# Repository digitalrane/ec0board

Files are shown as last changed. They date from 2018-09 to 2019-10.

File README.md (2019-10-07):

ec0board
========

ec0board is a personal project to replace the dead control board in my otherwise landfill Kogan TKL mechanical keyboard.
It was designed to occupy the exact same physical dimensions, and have the exact same key switch spacing as the original board, however has a much more powerful user-controlled MCU.
The MCU used is an AT90USB1286, chosen for the number of GPIOs, enabling NKRO to be achieved. It uses a diode matrix to connect the key switches, and takes Cherry-MX compatible key switches (I use browns).
Support is being added to the open source QMK firmware for this board, as the intention is to run a completely open keyboard replacement.

The board supports a switchable backlight, and additional RGB LED underneath the board (to see if the controller is alive, basically) and switchable backlights for the Fn, Caps, Scroll and Num lock keys independently to the main backlight.

This board uses custom footprints and 3d models for the following. If you find any of them missing from this repository, please file an issue.
* Cherry MX Brown switch model and footprint
* AT90USB1286 model and footprint
* Ingwaz rune (because I like to ensure runes or sigils cover my electronics for great ~ mystical power ~)

Versions
========

* v0: Original prototype, ended up not working reliably because I goofed the electron-herding aspects of this version.
* v1: Original replacement. Found the Micro USB connector to be flimsy, because Micro USB is a bit crap. Also had a testing RGB LED space,
  which never worked right. Other than that, fairly reliable, but still relied on the Kogan TKL or similar cheap Aliexpress/eBay donor KB.
* v2: Never released or manufactured, added standalone supports, rerouted entire keyboard to use newly added standard KiCad key switch
  footprints, generally cleaned up routing. Started moving toward a Mini USB connector to address connector stability.
* v3: Decided to use USB-C during a dream, so rewired the whole power supply and USB connection section. Further routing improvements.
  Cleaned up all footprints, values, and added better more descriptive values to components so a proper BOM could be generated. Generated a
  proper BOM with the Interactive HTML BOM KiCad plugin. Updated everything for KiCad 5.1 and added some more 3D models. All required
  libraries are now in KiCad or this repo.

Firmware
========

This keyboard uses QMK, and a board definition and configuration is included in the `qmk_ec0board` directory. Drop this into QMK and set
your keyboard type to 'ec0board' on the make commandline as documented [here](https://beta.docs.qmk.fm/detailed-guides/getting_started_make_guide).

e.g.:
`make ec0board`

Flashing
========

Programming of the firmware is done via the ISP header. You will need a standard AVR ISP programmer, I use an Olimex unit. They keyboard
should not be powered via USB whilst flashing, but you won't get magic smoke if you do it accidentally (yeah I tried it, so what, are you a
cop?).

Fuses
=====

The fuses on your AT90USB1286 should be set for external crystal oscillator operation, with JTAG disabled, to free up enough GPIOs. We
also want SPIEN set so we can use the ISP to flash/recover the chip.

The fules should be set to -
(E:F3, H:D9, L:DE)

BOM
===

Thanks to the wonderful [InteractiveHtmlBom](https://github.com/openscopeproject/InteractiveHtmlBom) KiCad plugin, this repository now
contains a really nice HTML BOM. You can clone this repo and browse it locally in the `bom` directory, or download/view it from
[here](https://rawcdn.githack.com/devec0/ec0board/master/bom/ibom.html).

For U1, AT90USB1286 is the sensible option, because no keyboard needs the host mode support of AT90USB1287.
If you need host mode, you're an absolute maniac. I want to know what you're up to, get in touch!

TODO
====

* Finish code for lighting backlight behind Capslock, Scrolllock, Numlock and the Function key when engaged
* Finish code to get the Function key working correctly

And another thing
=================

<3

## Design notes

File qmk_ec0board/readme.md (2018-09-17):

# ec0board

ec0board

A QMK replacement board for various TK529U mechanical keyboards.
Tried and tested as a replacement PCB in the Kogan TKL.

Keyboard Maintainer: [ec0](https://github.com/devec0)
Hardware Supported: ec0board v1 PCB
Hardware Availability: [DIY](http://github.com/devec0/ec0board)

Make example for this keyboard (after setting up your build environment):

    make ec0board:default

See [build environment setup](https://docs.qmk.fm/build_environment_setup.html) then the [make instructions](https://docs.qmk.fm/make_instructions.html) for more information.

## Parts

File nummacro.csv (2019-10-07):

Id | Designator | Package | Quantity | Designation | Supplier and ref
1 | SW1 | SW_SPST_EVQQ2 | 1 | RESET
2 | SW2 | SW_SPST_EVQQ2 | 1 | HWB
3 | SW_ESC1 | SW_Cherry_MX1A_1.00u_PCB | 1 | ESC
4 | G*** | ingwaz | 1 | LOGO
5 | REF** | OSHW-Logo2_14.6x12mm_SilkScreen | 1 | OSHW-Logo2_14.6x12mm_SilkScreen
6 | J1 | USB_C_Receptacle_GCT_USB4085 | 1 | GCT USB4085
7 | D88 | D_PowerDI-123 | 1 | MBR130LSFT1G
8 | C8 | C_0805_2012Metric_Pad1.15x1.40mm_HandSolder | 1 | 10uF
9 | C7,C2,C3 | C_0805_2012Metric_Pad1.15x1.40mm_HandSolder | 3 | 100n
10 | D35,D50,D45,D40,D27,D22,D17,D11,D58,D18,D64,D68,D74,D75,D79,D84,D2,D7,D12,D82,D13,D1,D19,D71,D23,D65,D59,D53,D48,D43,D38,D32,D36,D76,D80,D85,D4,D9,D14,D20,D25,D30,D87,D28,D51,D56,D62,D66,D72,D77,D81,D86,D5,D10,D41,D21,D26,D31,D37,D42,D47,D52,D57,D63,D6,D16,D24,D29,D33,D39,D44,D49,D55,D60,D69,D46,D3,D8,D15,D34,D54,D61,D67,D73,D78,D83,D70 | D_MiniMELF | 87 | LL4148
11 | R5,R4 | R_0805_2012Metric_Pad1.15x1.40mm_HandSolder | 2 | 22r
12 | LED_TILDE1,LED_HOME1,LED_END1,LED_UP1,LED_DOWN1,LED_PAUSE1,LED_PGUP1,LED_PGDN1,LED_RIGHT1,LED_LEFT1,LED_F11,LED_DEL1,LED_INS1,LED_PRN1,LED_F12,LED_RCTL1,LED_BKSLSH1,LED_BKSPC1,LED_ENTER1,LED_RSHIFT1,LED_LSHIFT1,LED_SCRL1,LED_F2,LED_FN1,LED_FSLASH1,LED_COLON1,LED_F9,LED_UNDSCR1,LED_RSUP1,LED_LBRACE1,LED_QUOT1,LED_F10,LED_EQUAL1,LED_3,LED_I1,LED_P1,LED_PERIOD1,LED_RALT1,LED_0,LED_L1,LED_O1,LED_F8,LED_COMMA1,LED_9,LED_K1,LED_F7,LED_RBRACE1,LED_N1,LED_F6,LED_U1,LED_J1,LED_8,LED_7,LED_H1,LED_Y1,LED_F5,LED_SPACE1,LED_B1,LED_X1,LED_6,LED_D1,LED_F3,LED_4,LED_C1,LED_R1,LED_F0,LED_F4,LED_5,LED_V1,LED_T1,LED_G1,LED_S1,LED_LALT1,LED_W1,LED_Z1,LED_2,LED_F1,LED_A1,LED_Q1,LED_LSUP1,LED_1,LED_M1,LED_CAPS1,LED_E1,LED_ESC1,LED_LCTL1,LED_TAB1 | LED_D3.0mm | 87 | LED
13 | SW_LSHIFT1 | SW_Cherry_MX1A_2.25u_PCB | 1 | LSHIFT
14 | SW_ENTER1 | SW_Cherry_MX1A_2.25u_PCB | 1 | ENTER
15 | SW_RSHIFT1 | SW_Cherry_MX1A_2.75u_PCB | 1 | RSHIFT
16 | Q1 | SOT-23 | 1 | MMBT3904
17 | SW_9 | SW_Cherry_MX1A_1.00u_PCB | 1 | 9
18 | Y1 | Crystal_SMD_HC49-SD_HandSoldering | 1 | 16Mhz
19 | SW_RIGHT1 | SW_Cherry_MX1A_1.00u_PCB | 1 | RIGHT
20 | SW_8 | SW_Cherry_MX1A_1.00u_PCB | 1 | 8
21 | SW_7 | SW_Cherry_MX1A_1.00u_PCB | 1 | 7
22 | SW_6 | SW_Cherry_MX1A_1.00u_PCB | 1 | 6
23 | SW_5 | SW_Cherry_MX1A_1.00u_PCB | 1 | 5
24 | SW_4 | SW_Cherry_MX1A_1.00u_PCB | 1 | 4
25 | SW_3 | SW_Cherry_MX1A_1.00u_PCB | 1 | 3
26 | SW_2 | SW_Cherry_MX1A_1.00u_PCB | 1 | 2
27 | SW_1 | SW_Cherry_MX1A_1.00u_PCB | 1 | 1
28 | C6 | C_0805_2012Metric_Pad1.15x1.40mm_HandSolder | 1 | 1uF
29 | C5,C4 | C_0805_2012Metric_Pad1.15x1.40mm_HandSolder | 2 | 22pF
30 | CON1 | PinHeader_2x03_P2.54mm_Vertical | 1 | ISP
31 | R41,R8,R7,R6,R81,R82,R83,R84,R11,R12,R13,R14,R15,R16,R17,R18,R73,R63,R65,R20,R21,R22,R23,R24,R25,R26,R27,R28,R29,R64,R19,R32,R33,R34,R35,R36,R37,R38,R39,R40,R9,R30,R47,R48,R49,R50,R51,R53,R54,R55,R56,R46,R58,R59,R60,R61,R89,R90,R91,R92,R93,R57,R31,R67,R68,R69,R70,R71,R72,R62,R74,R75,R76,R77,R78,R79,R80,R52,R42,R43,R44,R66,R45,R85,R86,R87,R88 | R_0805_2012Metric_Pad1.15x1.40mm_HandSolder | 87 | 470
32 | U1 | QFP80P1600X1600X120-64N | 1 | AT90USB1286
33 | R2,R3 | R_0805_2012Metric_Pad1.15x1.40mm_HandSolder | 2 | 5.1k
34 | SW_A1 | SW_Cherry_MX1A_1.00u_PCB | 1 | A
35 | SW_B1 | SW_Cherry_MX1A_1.00u_PCB | 1 | B
36 | SW_BKSPC1 | SW_Cherry_MX1A_2.00u_PCB | 1 | BKSPC
37 | SW_BSLSH1 | SW_Cherry_MX1A_1.50u_PCB | 1 | BSLSH
38 | SW_C1 | SW_Cherry_MX1A_1.00u_PCB | 1 | C
39 | SW_CAPS1 | SW_Cherry_MX1A_1.75u_PCB | 1 | CAPS
40 | SW_COLON1 | SW_Cherry_MX1A_1.00u_PCB | 1 | COLON
41 | SW_COMMA1 | SW_Cherry_MX1A_1.00u_PCB | 1 | COMMA
42 | SW_D1 | SW_Cherry_MX1A_1.00u_PCB | 1 | D
43 | SW_DEL1 | SW_Cherry_MX1A_1.00u_PCB | 1 | DEL
44 | SW_DOWN1 | SW_Cherry_MX1A_1.00u_PCB | 1 | DOWN
45 | SW_E1 | SW_Cherry_MX1A_1.00u_PCB | 1 | E
46 | SW_END1 | SW_Cherry_MX1A_1.00u_PCB | 1 | END
47 | SW_EQUAL1 | SW_Cherry_MX1A_1.00u_PCB | 1 | EQUAL
48 | SW_F1 | SW_Cherry_MX1A_1.00u_PCB | 1 | F1
49 | SW_F2 | SW_Cherry_MX1A_1.00u_PCB | 1 | F2
50 | SW_F3 | SW_Cherry_MX1A_1.00u_PCB | 1 | F3
51 | SW_F4 | SW_Cherry_MX1A_1.00u_PCB | 1 | F4
52 | SW_F5 | SW_Cherry_MX1A_1.00u_PCB | 1 | F5
53 | SW_F6 | SW_Cherry_MX1A_1.00u_PCB | 1 | F6
54 | SW_F7 | SW_Cherry_MX1A_1.00u_PCB | 1 | F7
55 | SW_F8 | SW_Cherry_MX1A_1.00u_PCB | 1 | F8
56 | SW_F9 | SW_Cherry_MX1A_1.00u_PCB | 1 | F9
57 | SW_F10 | SW_Cherry_MX1A_1.00u_PCB | 1 | F10
58 | SW_F11 | SW_Cherry_MX1A_1.00u_PCB | 1 | F11
59 | SW_F12 | SW_Cherry_MX1A_1.00u_PCB | 1 | F12
60 | SW_FSLASH1 | SW_Cherry_MX1A_1.00u_PCB | 1 | FSLASH
61 | SW_FUNC1 | SW_Cherry_MX1A_1.25u_PCB | 1 | FUNC
62 | SW_G1 | SW_Cherry_MX1A_1.00u_PCB | 1 | G
63 | SW_H1 | SW_Cherry_MX1A_1.00u_PCB | 1 | H
64 | SW_HOME1 | SW_Cherry_MX1A_1.00u_PCB | 1 | HOME
65 | SW_I1 | SW_Cherry_MX1A_1.00u_PCB | 1 | I
66 | SW_INS1 | SW_Cherry_MX1A_1.00u_PCB | 1 | INS
67 | SW_J1 | SW_Cherry_MX1A_1.00u_PCB | 1 | J
68 | SW_K1 | SW_Cherry_MX1A_1.00u_PCB | 1 | K
69 | SW_L1 | SW_Cherry_MX1A_1.00u_PCB | 1 | L
70 | SW_LALT1 | SW_Cherry_MX1A_1.25u_PCB | 1 | LALT
71 | SW_LBRACE1 | SW_Cherry_MX1A_1.00u_PCB | 1 | LBRACE
72 | SW_LCTRL1 | SW_Cherry_MX1A_1.25u_PCB | 1 | LCTRL
73 | SW_LEFT1 | SW_Cherry_MX1A_1.00u_PCB | 1 | LEFT
74 | SW_LSUP1 | SW_Cherry_MX1A_1.25u_PCB | 1 | LSUP
75 | SW_M1 | SW_Cherry_MX1A_1.00u_PCB | 1 | M
76 | SW_N1 | SW_Cherry_MX1A_1.00u_PCB | 1 | N
77 | SW_O1 | SW_Cherry_MX1A_1.00u_PCB | 1 | O
78 | SW_P1 | SW_Cherry_MX1A_1.00u_PCB | 1 | P
79 | SW_PAUSE1 | SW_Cherry_MX1A_1.00u_PCB | 1 | PAUSE
80 | SW_PERIOD1 | SW_Cherry_MX1A_1.00u_PCB | 1 | PERIOD
81 | SW_PGDN1 | SW_Cherry_MX1A_1.00u_PCB | 1 | PGDN
82 | SW_PGUP1 | SW_Cherry_MX1A_1.00u_PCB | 1 | PGUP
83 | SW_PRINT1 | SW_Cherry_MX1A_1.00u_PCB | 1 | PRINT
84 | SW_Q1 | SW_Cherry_MX1A_1.00u_PCB | 1 | Q
85 | SW_QUOT1 | SW_Cherry_MX1A_1.00u_PCB | 1 | QUOT
86 | SW_R1 | SW_Cherry_MX1A_1.00u_PCB | 1 | R
87 | SW_RALT1 | SW_Cherry_MX1A_1.25u_PCB | 1 | RALT
88 | SW_RBRACE1 | SW_Cherry_MX1A_1.00u_PCB | 1 | RBRACE
89 | SW_RCTL1 | SW_Cherry_MX1A_1.25u_PCB | 1 | RCTL
90 | SW_RSUP1 | SW_Cherry_MX1A_1.25u_PCB | 1 | RSUP
91 | SW_S1 | SW_Cherry_MX1A_1.00u_PCB | 1 | S
92 | SW_SCROLL1 | SW_Cherry_MX1A_1.00u_PCB | 1 | SCROLL
93 | SW_SPACE1 | SW_Cherry_MX1A_6.25u_PCB | 1 | SPACE
94 | SW_T1 | SW_Cherry_MX1A_1.00u_PCB | 1 | T
95 | SW_TAB1 | SW_Cherry_MX1A_1.50u_PCB | 1 | TAB
96 | SW_TILDE1 | SW_Cherry_MX1A_1.00u_PCB | 1 | TILDE
97 | SW_U1 | SW_Cherry_MX1A_1.00u_PCB | 1 | U
98 | SW_UNDSCR1 | SW_Cherry_MX1A_1.00u_PCB | 1 | UNDSCR
99 | SW_UP1 | SW_Cherry_MX1A_1.00u_PCB | 1 | UP
100 | SW_V1 | SW_Cherry_MX1A_1.00u_PCB | 1 | V
101 | SW_W1 | SW_Cherry_MX1A_1.00u_PCB | 1 | W
102 | SW_X1 | SW_Cherry_MX1A_1.00u_PCB | 1 | X
103 | SW_Y1 | SW_Cherry_MX1A_1.00u_PCB | 1 | Y
104 | SW_Z1 | SW_Cherry_MX1A_1.00u_PCB | 1 | Z
105 | SW_F0 | SW_Cherry_MX1A_1.00u_PCB | 1 | F
106 | SW_10 | SW_Cherry_MX1A_1.00u_PCB | 1 | 0
107 | R10 | R_0805_2012Metric_Pad1.15x1.40mm_HandSolder | 1 | 1K

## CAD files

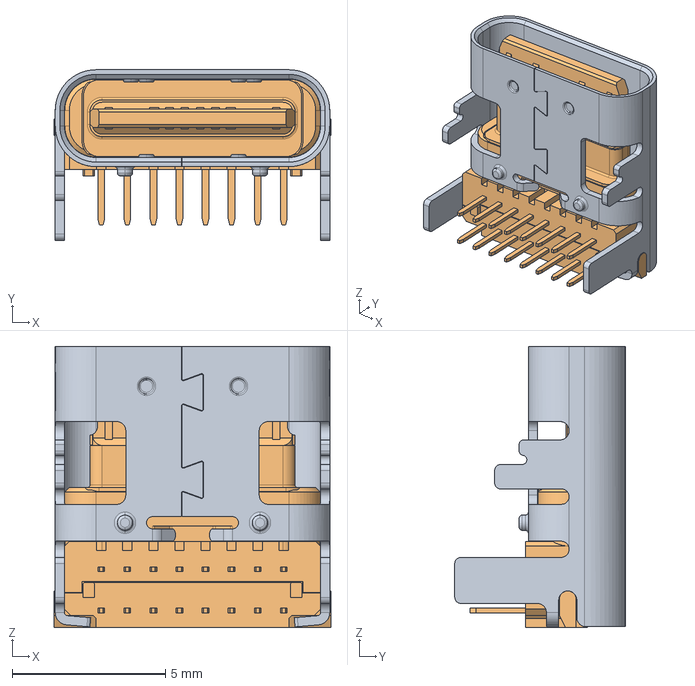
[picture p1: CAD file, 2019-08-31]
USB4085-GF-A.stp
9.03 x 5.56 x 9.17 mm
ÇÐ³ý-ÀÉì1
Í¹Ì¨-ÀÉì1

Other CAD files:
USB4085-GF-A.stl

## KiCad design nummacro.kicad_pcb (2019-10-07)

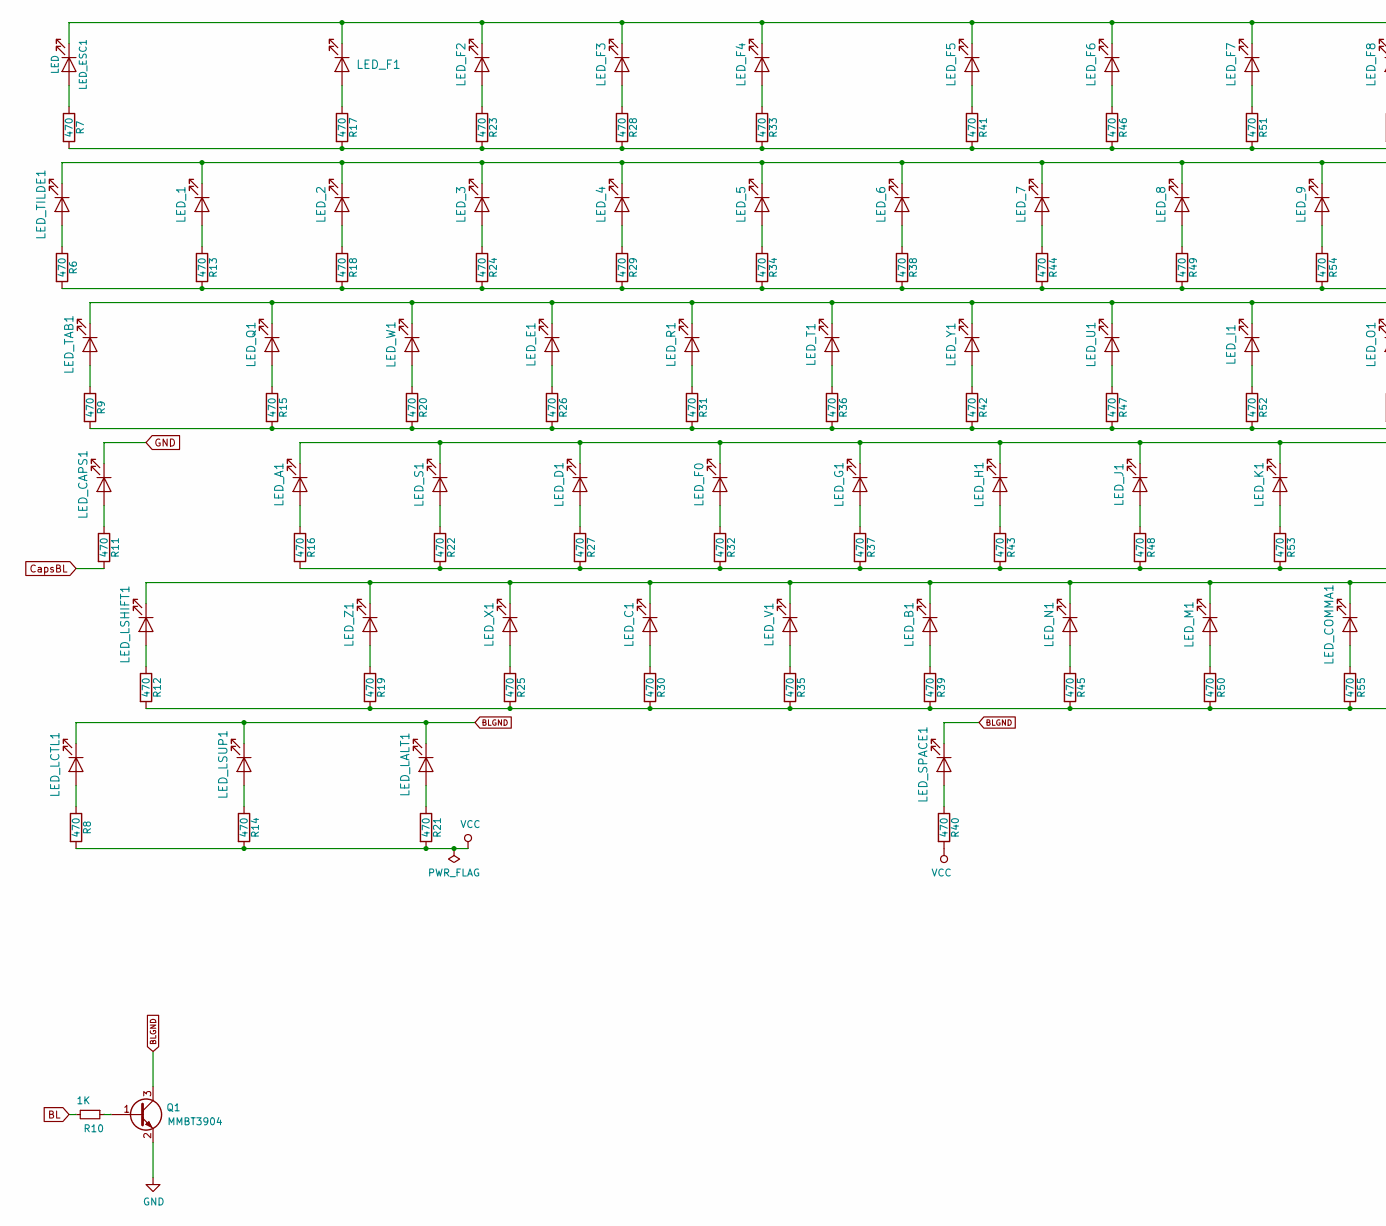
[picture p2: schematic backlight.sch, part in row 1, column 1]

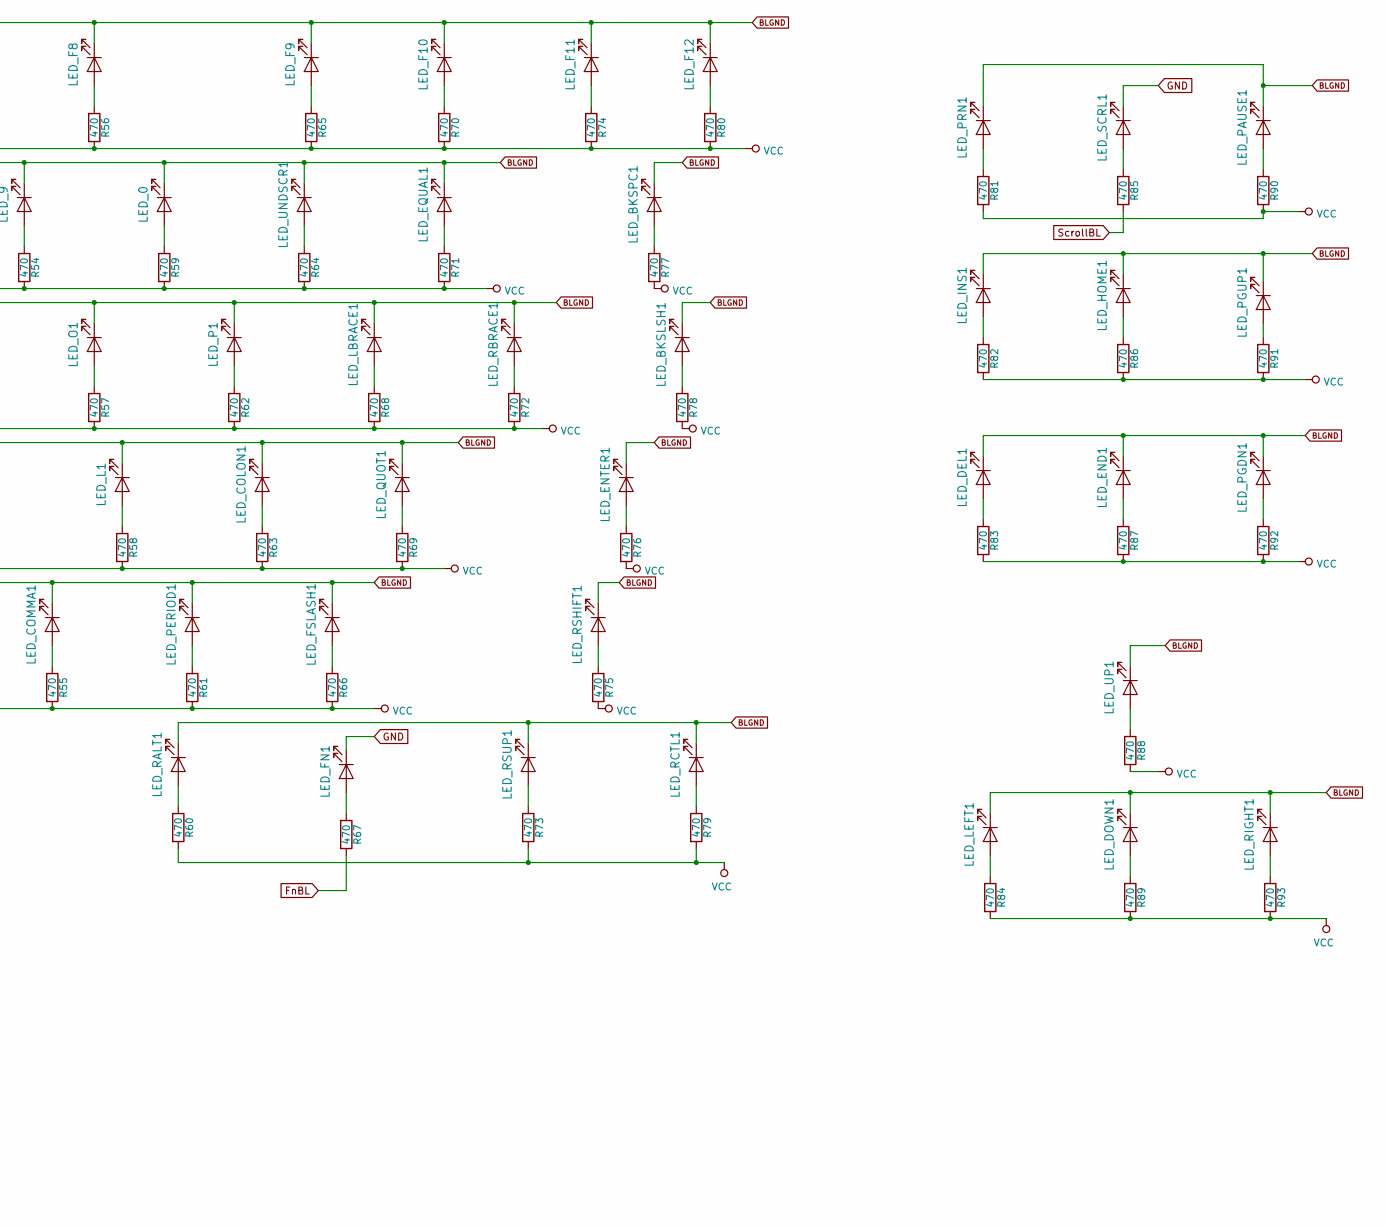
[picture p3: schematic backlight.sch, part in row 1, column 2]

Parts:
LED_0, LED_1, LED_2, LED_3, LED_4, LED_5, LED_6, LED_7, LED_8, LED_9: LED; LED_D3.0mm
LED_A1: LED; LED_D3.0mm
LED_B1: LED; LED_D3.0mm
LED_BKSLSH1: LED; LED_D3.0mm
LED_BKSPC1: LED; LED_D3.0mm
LED_C1: LED; LED_D3.0mm
LED_CAPS1: LED; LED_D3.0mm
LED_COLON1: LED; LED_D3.0mm
LED_COMMA1: LED; LED_D3.0mm
LED_D1: LED; LED_D3.0mm
LED_DEL1: LED; LED_D3.0mm
LED_DOWN1: LED; LED_D3.0mm
LED_E1: LED; LED_D3.0mm
LED_END1: LED; LED_D3.0mm
LED_ENTER1: LED; LED_D3.0mm
LED_EQUAL1: LED; LED_D3.0mm
LED_ESC1: LED; LED_D3.0mm
LED_F0, LED_F1, LED_F2, LED_F3, LED_F4, LED_F5, LED_F6, LED_F7, LED_F8, LED_F9, LED_F10, LED_F11, LED_F12: LED; LED_D3.0mm
LED_FN1: LED; LED_D3.0mm
LED_FSLASH1: LED; LED_D3.0mm
LED_G1: LED; LED_D3.0mm
LED_H1: LED; LED_D3.0mm
LED_HOME1: LED; LED_D3.0mm
LED_I1: LED; LED_D3.0mm
LED_INS1: LED; LED_D3.0mm
LED_J1: LED; LED_D3.0mm
LED_K1: LED; LED_D3.0mm
LED_L1: LED; LED_D3.0mm
LED_LALT1: LED; LED_D3.0mm
LED_LBRACE1: LED; LED_D3.0mm
LED_LCTL1: LED; LED_D3.0mm
LED_LEFT1: LED; LED_D3.0mm
LED_LSHIFT1: LED; LED_D3.0mm
LED_LSUP1: LED; LED_D3.0mm
LED_M1: LED; LED_D3.0mm
LED_N1: LED; LED_D3.0mm
LED_O1: LED; LED_D3.0mm
LED_P1: LED; LED_D3.0mm
LED_PAUSE1: LED; LED_D3.0mm
LED_PERIOD1: LED; LED_D3.0mm
LED_PGDN1: LED; LED_D3.0mm
LED_PGUP1: LED; LED_D3.0mm
LED_PRN1: LED; LED_D3.0mm
LED_Q1: LED; LED_D3.0mm
LED_QUOT1: LED; LED_D3.0mm
LED_R1: LED; LED_D3.0mm
LED_RALT1: LED; LED_D3.0mm
LED_RBRACE1: LED; LED_D3.0mm
LED_RCTL1: LED; LED_D3.0mm
LED_RIGHT1: LED; LED_D3.0mm
LED_RSHIFT1: LED; LED_D3.0mm
LED_RSUP1: LED; LED_D3.0mm
LED_S1: LED; LED_D3.0mm
LED_SCRL1: LED; LED_D3.0mm
LED_SPACE1: LED; LED_D3.0mm
LED_T1: LED; LED_D3.0mm
LED_TAB1: LED; LED_D3.0mm
LED_TILDE1: LED; LED_D3.0mm
LED_U1: LED; LED_D3.0mm
LED_UNDSCR1: LED; LED_D3.0mm
LED_UP1: LED; LED_D3.0mm
LED_V1: LED; LED_D3.0mm
LED_W1: LED; LED_D3.0mm
LED_X1: LED; LED_D3.0mm
LED_Y1: LED; LED_D3.0mm
LED_Z1: LED; LED_D3.0mm
Q1: MMBT3904; SOT-23
R6, R7, R8, R9, R11, R12, R13, R14, R15, R16, R17, R18, R19, R20, R21, R22, R23, R24, R25, R26, R27, R28, R29, R30, R31, R32, R33, R34, R35, R36, R37, R38, R39, R40, R41, R42, R43, R44, R45, R46, R47, R48, R49, R50, R51, R52, R53, R54, R55, R56, R57, R58, R59, R60, R61, R62, R63, R64, R65, R66, R67, R68, R69, R70, R71, R72, R73, R74, R75, R76, R77, R78, R79, R80, R81, R82, R83, R84, R85, R86, R87, R88, R89, R90, R91, R92, R93: 470; R_0805_2012Metric_Pad1.15x1.40mm_HandSolder
R10: 1K; R_0805_2012Metric_Pad1.15x1.40mm_HandSolder

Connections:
BL: R10.2; also elsewhere on the board
BLGND: LED_0.1 (K), LED_1.1 (K), LED_2.1 (K), LED_3.1 (K), LED_4.1 (K), LED_5.1 (K), LED_6.1 (K), LED_7.1 (K), LED_8.1 (K), LED_9.1 (K), LED_A1.1 (K), LED_B1.1 (K), LED_BKSLSH1.1 (K), LED_BKSPC1.1 (K), LED_C1.1 (K), LED_COLON1.1 (K), LED_COMMA1.1 (K), LED_D1.1 (K), LED_DEL1.1 (K), LED_DOWN1.1 (K), LED_E1.1 (K), LED_END1.1 (K), LED_ENTER1.1 (K), LED_EQUAL1.1 (K), LED_ESC1.1 (K), LED_F0.1 (K), LED_F1.1 (K), LED_F2.1 (K), LED_F3.1 (K), LED_F4.1 (K), LED_F5.1 (K), LED_F6.1 (K), LED_F7.1 (K), LED_F8.1 (K), LED_F9.1 (K), LED_F10.1 (K), LED_F11.1 (K), LED_F12.1 (K), LED_FSLASH1.1 (K), LED_G1.1 (K), LED_H1.1 (K), LED_HOME1.1 (K), LED_I1.1 (K), LED_INS1.1 (K), LED_J1.1 (K), LED_K1.1 (K), LED_L1.1 (K), LED_LALT1.1 (K), LED_LBRACE1.1 (K), LED_LCTL1.1 (K), LED_LEFT1.1 (K), LED_LSHIFT1.1 (K), LED_LSUP1.1 (K), LED_M1.1 (K), LED_N1.1 (K), LED_O1.1 (K), LED_P1.1 (K), LED_PAUSE1.1 (K), LED_PERIOD1.1 (K), LED_PGDN1.1 (K), LED_PGUP1.1 (K), LED_PRN1.1 (K), LED_Q1.1 (K), LED_QUOT1.1 (K), LED_R1.1 (K), LED_RALT1.1 (K), LED_RBRACE1.1 (K), LED_RCTL1.1 (K), LED_RIGHT1.1 (K), LED_RSHIFT1.1 (K), LED_RSUP1.1 (K), LED_S1.1 (K), LED_SPACE1.1 (K), LED_T1.1 (K), LED_TAB1.1 (K), LED_TILDE1.1 (K), LED_U1.1 (K), LED_UNDSCR1.1 (K), LED_UP1.1 (K), LED_V1.1 (K), LED_W1.1 (K), LED_X1.1 (K), LED_Y1.1 (K), LED_Z1.1 (K), Q1.3 (C)
CapsBL: R11.2; also elsewhere on the board
FnBL: R67.2; also elsewhere on the board
GND: LED_CAPS1.1 (K), LED_FN1.1 (K), LED_SCRL1.1 (K), Q1.2 (E); also elsewhere on the board
unnamed: LED_0.2 (A), R59.1
unnamed: LED_1.2 (A), R13.1
unnamed: LED_2.2 (A), R18.1
unnamed: LED_3.2 (A), R24.1
unnamed: LED_4.2 (A), R29.1
unnamed: LED_5.2 (A), R34.1
unnamed: LED_6.2 (A), R38.1
unnamed: LED_7.2 (A), R44.1
unnamed: LED_8.2 (A), R49.1
unnamed: LED_9.2 (A), R54.1
unnamed: LED_A1.2 (A), R16.1
unnamed: LED_B1.2 (A), R39.1
unnamed: LED_BKSLSH1.2 (A), R78.1
unnamed: LED_BKSPC1.2 (A), R77.1
unnamed: LED_C1.2 (A), R30.1
unnamed: LED_CAPS1.2 (A), R11.1
unnamed: LED_COLON1.2 (A), R63.1
unnamed: LED_COMMA1.2 (A), R55.1
unnamed: LED_D1.2 (A), R27.1
unnamed: LED_DEL1.2 (A), R83.1
unnamed: LED_DOWN1.2 (A), R89.1
unnamed: LED_E1.2 (A), R26.1
unnamed: LED_END1.2 (A), R87.1
unnamed: LED_ENTER1.2 (A), R76.1
unnamed: LED_EQUAL1.2 (A), R71.1
unnamed: LED_ESC1.2 (A), R7.1
unnamed: LED_F0.2 (A), R32.1
unnamed: LED_F1.2 (A), R17.1
unnamed: LED_F2.2 (A), R23.1
unnamed: LED_F3.2 (A), R28.1
unnamed: LED_F4.2 (A), R33.1
unnamed: LED_F5.2 (A), R41.1
unnamed: LED_F6.2 (A), R46.1
unnamed: LED_F7.2 (A), R51.1
unnamed: LED_F8.2 (A), R56.1
unnamed: LED_F9.2 (A), R65.1
unnamed: LED_F10.2 (A), R70.1
unnamed: LED_F11.2 (A), R74.1
unnamed: LED_F12.2 (A), R80.1
unnamed: LED_FN1.2 (A), R67.1
unnamed: LED_FSLASH1.2 (A), R66.1
unnamed: LED_G1.2 (A), R37.1
unnamed: LED_H1.2 (A), R43.1
unnamed: LED_HOME1.2 (A), R86.1
unnamed: LED_I1.2 (A), R52.1
unnamed: LED_INS1.2 (A), R82.1
unnamed: LED_J1.2 (A), R48.1
unnamed: LED_K1.2 (A), R53.1
unnamed: LED_L1.2 (A), R58.1
unnamed: LED_LALT1.2 (A), R21.1
unnamed: LED_LBRACE1.2 (A), R68.1
unnamed: LED_LCTL1.2 (A), R8.1
unnamed: LED_LEFT1.2 (A), R84.1
unnamed: LED_LSHIFT1.2 (A), R12.1
unnamed: LED_LSUP1.2 (A), R14.1
unnamed: LED_M1.2 (A), R50.1
unnamed: LED_N1.2 (A), R45.1
unnamed: LED_O1.2 (A), R57.1
unnamed: LED_P1.2 (A), R62.1
unnamed: LED_PAUSE1.2 (A), R90.1
unnamed: LED_PERIOD1.2 (A), R61.1
unnamed: LED_PGDN1.2 (A), R92.1
unnamed: LED_PGUP1.2 (A), R91.1
unnamed: LED_PRN1.2 (A), R81.1
unnamed: LED_Q1.2 (A), R15.1
unnamed: LED_QUOT1.2 (A), R69.1
unnamed: LED_R1.2 (A), R31.1
unnamed: LED_RALT1.2 (A), R60.1
unnamed: LED_RBRACE1.2 (A), R72.1
unnamed: LED_RCTL1.2 (A), R79.1
unnamed: LED_RIGHT1.2 (A), R93.1
unnamed: LED_RSHIFT1.2 (A), R75.1
unnamed: LED_RSUP1.2 (A), R73.1
unnamed: LED_S1.2 (A), R22.1
unnamed: LED_SCRL1.2 (A), R85.1
unnamed: LED_SPACE1.2 (A), R40.1
unnamed: LED_T1.2 (A), R36.1
unnamed: LED_TAB1.2 (A), R9.1
unnamed: LED_TILDE1.2 (A), R6.1
unnamed: LED_U1.2 (A), R47.1
unnamed: LED_UNDSCR1.2 (A), R64.1
unnamed: LED_UP1.2 (A), R88.1
unnamed: LED_V1.2 (A), R35.1
unnamed: LED_W1.2 (A), R20.1
unnamed: LED_X1.2 (A), R25.1
unnamed: LED_Y1.2 (A), R42.1
unnamed: LED_Z1.2 (A), R19.1
unnamed: Q1.1 (B), R10.1
ScrollBL: R85.2; also elsewhere on the board
VCC: R6.2, R7.2, R8.2, R9.2, R12.2, R13.2, R14.2, R15.2, R16.2, R17.2, R18.2, R19.2, R20.2, R21.2, R22.2, R23.2, R24.2, R25.2, R26.2, R27.2, R28.2, R29.2, R30.2, R31.2, R32.2, R33.2, R34.2, R35.2, R36.2, R37.2, R38.2, R39.2, R40.2, R41.2, R42.2, R43.2, R44.2, R45.2, R46.2, R47.2, R48.2, R49.2, R50.2, R51.2, R52.2, R53.2, R54.2, R55.2, R56.2, R57.2, R58.2, R59.2, R60.2, R61.2, R62.2, R63.2, R64.2, R65.2, R66.2, R68.2, R69.2, R70.2, R71.2, R72.2, R73.2, R74.2, R75.2, R76.2, R77.2, R78.2, R79.2, R80.2, R81.2, R82.2, R83.2, R84.2, R86.2, R87.2, R88.2, R89.2, R90.2, R91.2, R92.2, R93.2; also elsewhere on the board

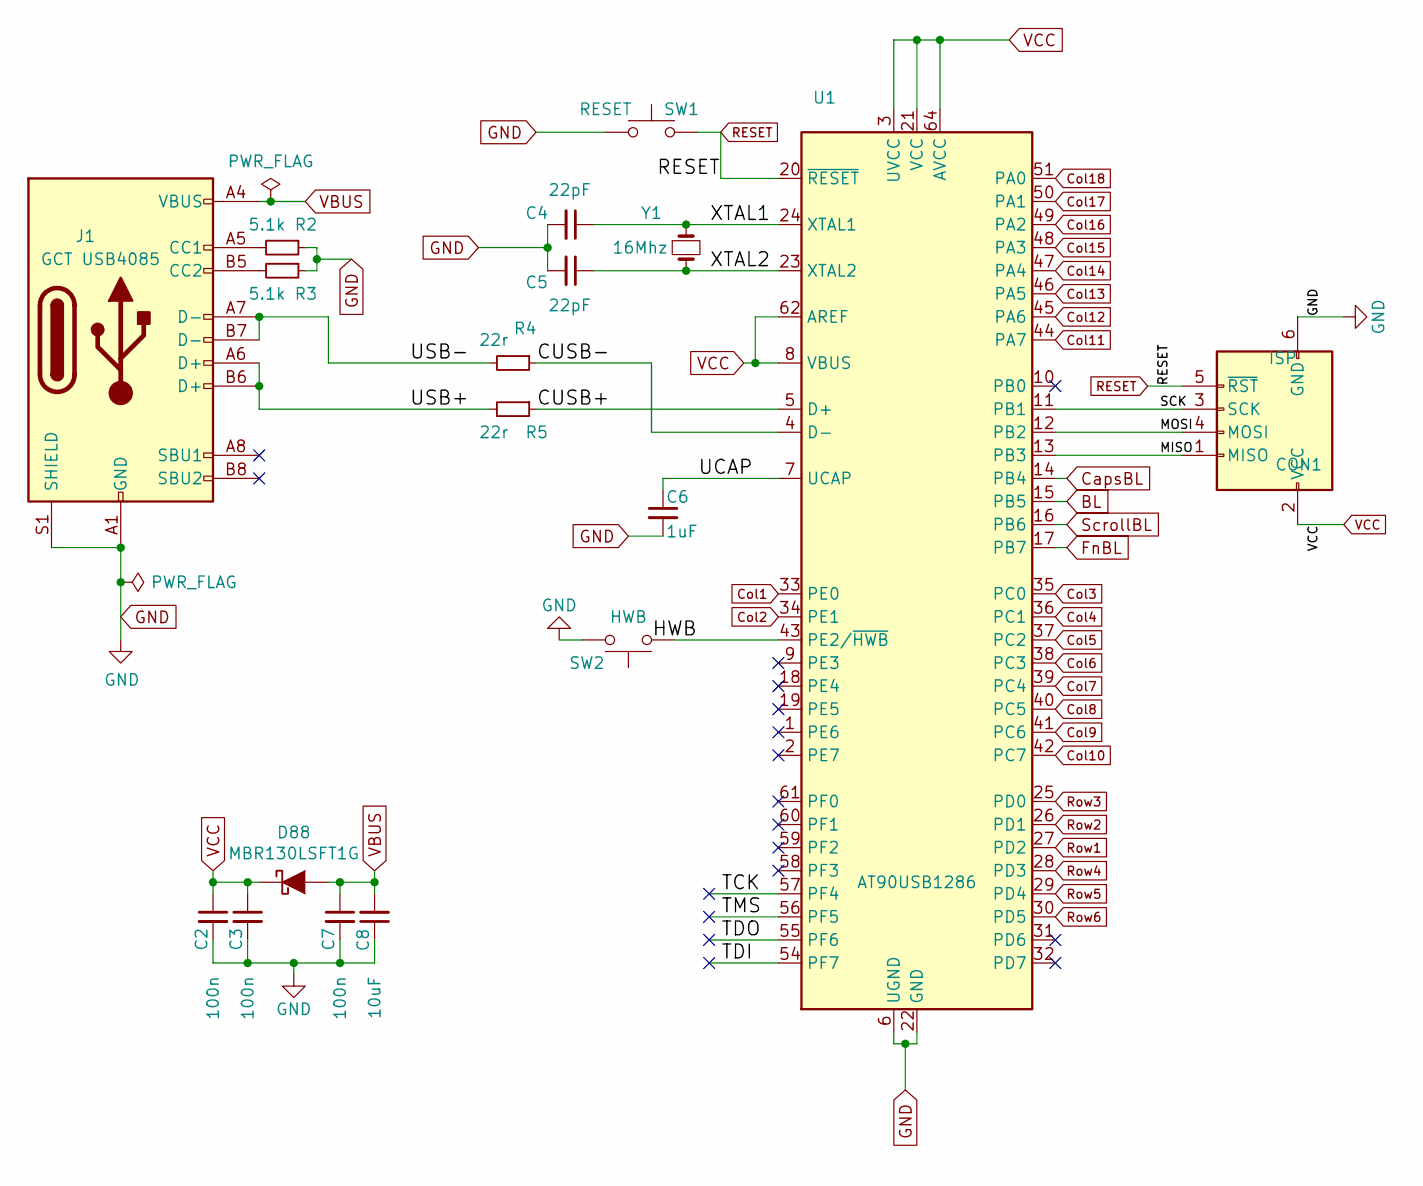
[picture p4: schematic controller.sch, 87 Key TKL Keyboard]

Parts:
C2, C3, C7: 100n; C_0805_2012Metric_Pad1.15x1.40mm_HandSolder
C4, C5: 22pF; C_0805_2012Metric_Pad1.15x1.40mm_HandSolder
C6: 1uF; C_0805_2012Metric_Pad1.15x1.40mm_HandSolder
C8: 10uF; C_0805_2012Metric_Pad1.15x1.40mm_HandSolder
CON1: ISP; PinHeader_2x03_P2.54mm_Vertical
D88: MBR130LSFT1G; D_PowerDI-123
J1: GCT USB4085; USB_C_Receptacle_GCT_USB4085
R2, R3: 5.1k; R_0805_2012Metric_Pad1.15x1.40mm_HandSolder
R4, R5: 22r; R_0805_2012Metric_Pad1.15x1.40mm_HandSolder
SW1: RESET; SW_SPST_B3SL-1002P
SW2: HWB; SW_SPST_B3SL-1002P
U1: AT90USB1286; QFP80P1600X1600X120-64N
Y1: 16Mhz; Crystal_SMD_HC49-SD_HandSoldering

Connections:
/controller/CUSB+: R5.1, U1.5 (D+)
/controller/CUSB-: R4.1, U1.4 (D-)
/controller/HWB: SW2.1, U1.43 (PE2/~HWB)
/controller/MISO: CON1.1 (MISO), U1.13 (PB3)
/controller/MOSI: CON1.4 (MOSI), U1.12 (PB2)
/controller/SCK: CON1.3 (SCK), U1.11 (PB1)
/controller/TCK: U1.57 (PF4)
/controller/TDI: U1.54 (PF7)
/controller/TDO: U1.55 (PF6)
/controller/TMS: U1.56 (PF5)
/controller/UCAP: C6.1, U1.7 (UCAP)
/controller/USB+: J1.A6 (D+), J1.B6 (D+), R5.2
/controller/USB-: J1.A7 (D-), J1.B7 (D-), R4.2
/controller/XTAL1: C4.1, U1.24 (XTAL1), Y1.1
/controller/XTAL2: C5.1, U1.23 (XTAL2), Y1.2
BL: U1.15 (PB5); also elsewhere on the board
CapsBL: U1.14 (PB4); also elsewhere on the board
Col1: U1.33 (PE0); also elsewhere on the board
Col2: U1.34 (PE1); also elsewhere on the board
Col3: U1.35 (PC0); also elsewhere on the board
Col4: U1.36 (PC1); also elsewhere on the board
Col5: U1.37 (PC2); also elsewhere on the board
Col6: U1.38 (PC3); also elsewhere on the board
Col7: U1.39 (PC4); also elsewhere on the board
Col8: U1.40 (PC5); also elsewhere on the board
Col9: U1.41 (PC6); also elsewhere on the board
Col10: U1.42 (PC7); also elsewhere on the board
Col11: U1.44 (PA7); also elsewhere on the board
Col12: U1.45 (PA6); also elsewhere on the board
Col13: U1.46 (PA5); also elsewhere on the board
Col14: U1.47 (PA4); also elsewhere on the board
Col15: U1.48 (PA3); also elsewhere on the board
Col16: U1.49 (PA2); also elsewhere on the board
Col17: U1.50 (PA1); also elsewhere on the board
Col18: U1.51 (PA0); also elsewhere on the board
FnBL: U1.17 (PB7); also elsewhere on the board
GND: C2.2, C3.2, C4.2, C5.2, C6.2, C7.2, C8.1, CON1.6 (GND), J1.A1 (GND), J1.A12 (GND), J1.B1 (GND), J1.B12 (GND), J1.S1 (SHIELD), R2.1, R3.1, SW1.1, SW2.2, U1.6 (UGND), U1.22 (GND), U1.53 (GND), U1.63 (GND); also elsewhere on the board
unnamed: J1.A5 (CC1), R2.2
unnamed: J1.B5 (CC2), R3.2
RESET: CON1.5 (~RST), SW1.2, U1.20 (~RESET)
Row1: U1.27 (PD2); also elsewhere on the board
Row2: U1.26 (PD1); also elsewhere on the board
Row3: U1.25 (PD0); also elsewhere on the board
Row4: U1.28 (PD3); also elsewhere on the board
Row5: U1.29 (PD4); also elsewhere on the board
Row6: U1.30 (PD5); also elsewhere on the board
ScrollBL: U1.16 (PB6); also elsewhere on the board
VBUS: C7.1, C8.2, D88.2 (A), J1.A4 (VBUS), J1.A9 (VBUS), J1.B4 (VBUS), J1.B9 (VBUS)
VCC: C2.1, C3.1, CON1.2 (VCC), D88.1 (K), U1.3 (UVCC), U1.8 (VBUS), U1.21 (VCC), U1.52 (VCC), U1.62 (AREF), U1.64 (AVCC); also elsewhere on the board

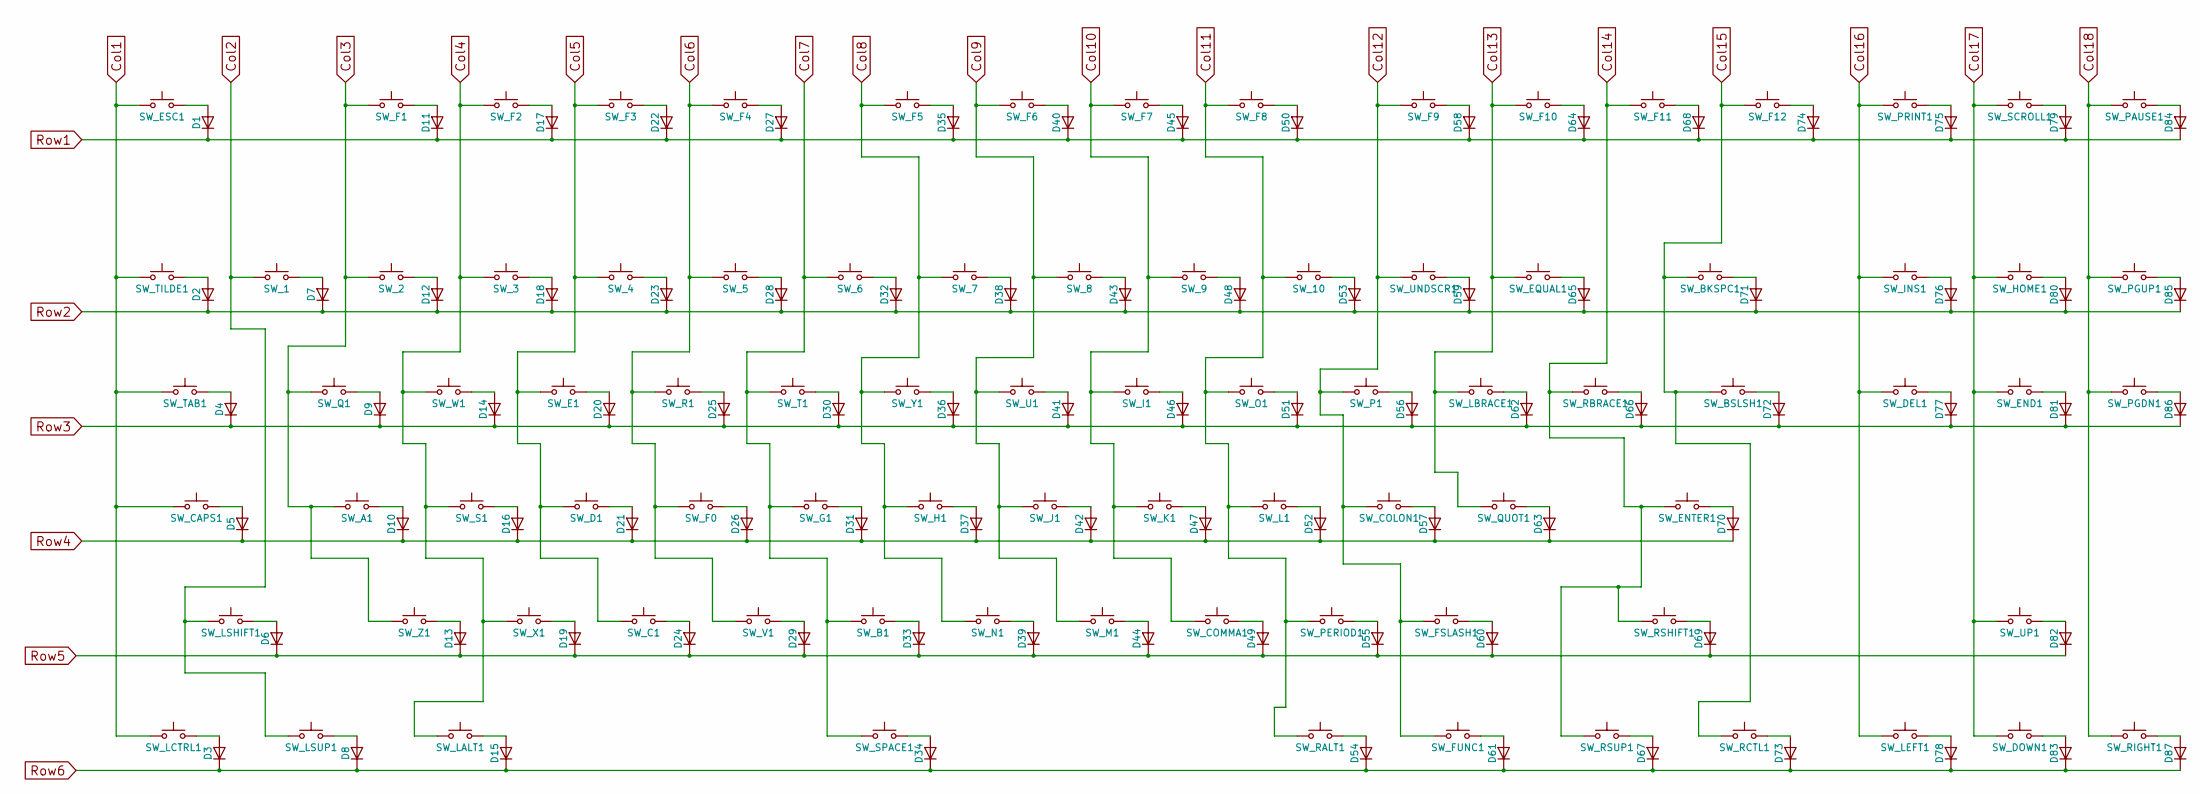
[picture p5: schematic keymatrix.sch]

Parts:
D1, D2, D3, D4, D5, D6, D7, D8, D9, D10, D11, D12, D13, D14, D15, D16, D17, D18, D19, D20, D21, D22, D23, D24, D25, D26, D27, D28, D29, D30, D31, D32, D33, D34, D35, D36, D37, D38, D39, D40, D41, D42, D43, D44, D45, D46, D47, D48, D49, D50, D51, D52, D53, D54, D55, D56, D57, D58, D59, D60, D61, D62, D63, D64, D65, D66, D67, D68, D69, D70, D71, D72, D73, D74, D75, D76, D77, D78, D79, D80, D81, D82, D83, D84, D85, D86, D87: LL4148; D_MiniMELF
SW_1: 1; SW_Cherry_MX1A_1.00u_PCB
SW_2: 2; SW_Cherry_MX1A_1.00u_PCB
SW_3: 3; SW_Cherry_MX1A_1.00u_PCB
SW_4: 4; SW_Cherry_MX1A_1.00u_PCB
SW_5: 5; SW_Cherry_MX1A_1.00u_PCB
SW_6: 6; SW_Cherry_MX1A_1.00u_PCB
SW_7: 7; SW_Cherry_MX1A_1.00u_PCB
SW_8: 8; SW_Cherry_MX1A_1.00u_PCB
SW_9: 9; SW_Cherry_MX1A_1.00u_PCB
SW_10: 0; SW_Cherry_MX1A_1.00u_PCB
SW_A1: A; SW_Cherry_MX1A_1.00u_PCB
SW_B1: B; SW_Cherry_MX1A_1.00u_PCB
SW_BKSPC1: BKSPC; SW_Cherry_MX1A_2.00u_PCB
SW_BSLSH1: BSLSH; SW_Cherry_MX1A_1.50u_PCB
SW_C1: C; SW_Cherry_MX1A_1.00u_PCB
SW_CAPS1: CAPS; SW_Cherry_MX1A_1.75u_PCB
SW_COLON1: COLON; SW_Cherry_MX1A_1.00u_PCB
SW_COMMA1: COMMA; SW_Cherry_MX1A_1.00u_PCB
SW_D1: D; SW_Cherry_MX1A_1.00u_PCB
SW_DEL1: DEL; SW_Cherry_MX1A_1.00u_PCB
SW_DOWN1: DOWN; SW_Cherry_MX1A_1.00u_PCB
SW_E1: E; SW_Cherry_MX1A_1.00u_PCB
SW_END1: END; SW_Cherry_MX1A_1.00u_PCB
SW_ENTER1: ENTER; SW_Cherry_MX1A_2.25u_PCB
SW_EQUAL1: EQUAL; SW_Cherry_MX1A_1.00u_PCB
SW_ESC1: ESC; SW_Cherry_MX1A_1.00u_PCB
SW_F0: F; SW_Cherry_MX1A_1.00u_PCB
SW_F1: F1; SW_Cherry_MX1A_1.00u_PCB
SW_F2: F2; SW_Cherry_MX1A_1.00u_PCB
SW_F3: F3; SW_Cherry_MX1A_1.00u_PCB
SW_F4: F4; SW_Cherry_MX1A_1.00u_PCB
SW_F5: F5; SW_Cherry_MX1A_1.00u_PCB
SW_F6: F6; SW_Cherry_MX1A_1.00u_PCB
SW_F7: F7; SW_Cherry_MX1A_1.00u_PCB
SW_F8: F8; SW_Cherry_MX1A_1.00u_PCB
SW_F9: F9; SW_Cherry_MX1A_1.00u_PCB
SW_F10: F10; SW_Cherry_MX1A_1.00u_PCB
SW_F11: F11; SW_Cherry_MX1A_1.00u_PCB
SW_F12: F12; SW_Cherry_MX1A_1.00u_PCB
SW_FSLASH1: FSLASH; SW_Cherry_MX1A_1.00u_PCB
SW_FUNC1: FUNC; SW_Cherry_MX1A_1.25u_PCB
SW_G1: G; SW_Cherry_MX1A_1.00u_PCB
SW_H1: H; SW_Cherry_MX1A_1.00u_PCB
SW_HOME1: HOME; SW_Cherry_MX1A_1.00u_PCB
SW_I1: I; SW_Cherry_MX1A_1.00u_PCB
SW_INS1: INS; SW_Cherry_MX1A_1.00u_PCB
SW_J1: J; SW_Cherry_MX1A_1.00u_PCB
SW_K1: K; SW_Cherry_MX1A_1.00u_PCB
SW_L1: L; SW_Cherry_MX1A_1.00u_PCB
SW_LALT1: LALT; SW_Cherry_MX1A_1.25u_PCB
SW_LBRACE1: LBRACE; SW_Cherry_MX1A_1.00u_PCB
SW_LCTRL1: LCTRL; SW_Cherry_MX1A_1.25u_PCB
SW_LEFT1: LEFT; SW_Cherry_MX1A_1.00u_PCB
SW_LSHIFT1: LSHIFT; SW_Cherry_MX1A_2.25u_PCB
SW_LSUP1: LSUP; SW_Cherry_MX1A_1.25u_PCB
SW_M1: M; SW_Cherry_MX1A_1.00u_PCB
SW_N1: N; SW_Cherry_MX1A_1.00u_PCB
SW_O1: O; SW_Cherry_MX1A_1.00u_PCB
SW_P1: P; SW_Cherry_MX1A_1.00u_PCB
SW_PAUSE1: PAUSE; SW_Cherry_MX1A_1.00u_PCB
SW_PERIOD1: PERIOD; SW_Cherry_MX1A_1.00u_PCB
SW_PGDN1: PGDN; SW_Cherry_MX1A_1.00u_PCB
SW_PGUP1: PGUP; SW_Cherry_MX1A_1.00u_PCB
SW_PRINT1: PRINT; SW_Cherry_MX1A_1.00u_PCB
SW_Q1: Q; SW_Cherry_MX1A_1.00u_PCB
SW_QUOT1: QUOT; SW_Cherry_MX1A_1.00u_PCB
SW_R1: R; SW_Cherry_MX1A_1.00u_PCB
SW_RALT1: RALT; SW_Cherry_MX1A_1.25u_PCB
SW_RBRACE1: RBRACE; SW_Cherry_MX1A_1.00u_PCB
SW_RCTL1: RCTL; SW_Cherry_MX1A_1.25u_PCB
SW_RIGHT1: RIGHT; SW_Cherry_MX1A_1.00u_PCB
SW_RSHIFT1: RSHIFT; SW_Cherry_MX1A_2.75u_PCB
SW_RSUP1: RSUP; SW_Cherry_MX1A_1.25u_PCB
SW_S1: S; SW_Cherry_MX1A_1.00u_PCB
SW_SCROLL1: SCROLL; SW_Cherry_MX1A_1.00u_PCB
SW_SPACE1: SPACE; SW_Cherry_MX1A_6.25u_PCB
SW_T1: T; SW_Cherry_MX1A_1.00u_PCB
SW_TAB1: TAB; SW_Cherry_MX1A_1.50u_PCB
SW_TILDE1: TILDE; SW_Cherry_MX1A_1.00u_PCB
SW_U1: U; SW_Cherry_MX1A_1.00u_PCB
SW_UNDSCR1: UNDSCR; SW_Cherry_MX1A_1.00u_PCB
SW_UP1: UP; SW_Cherry_MX1A_1.00u_PCB
SW_V1: V; SW_Cherry_MX1A_1.00u_PCB
SW_W1: W; SW_Cherry_MX1A_1.00u_PCB
SW_X1: X; SW_Cherry_MX1A_1.00u_PCB
SW_Y1: Y; SW_Cherry_MX1A_1.00u_PCB
SW_Z1: Z; SW_Cherry_MX1A_1.00u_PCB

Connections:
Col1: SW_CAPS1.2, SW_ESC1.2, SW_LCTRL1.2, SW_TAB1.2, SW_TILDE1.2; also elsewhere on the board
Col2: SW_1.2, SW_LSHIFT1.2, SW_LSUP1.2; also elsewhere on the board
Col3: SW_2.2, SW_A1.2, SW_F1.2, SW_Q1.2, SW_Z1.2; also elsewhere on the board
Col4: SW_3.2, SW_F2.2, SW_LALT1.2, SW_S1.2, SW_W1.2, SW_X1.2; also elsewhere on the board
Col5: SW_4.2, SW_C1.2, SW_D1.2, SW_E1.2, SW_F3.2; also elsewhere on the board
Col6: SW_5.2, SW_F0.2, SW_F4.2, SW_R1.2, SW_V1.2; also elsewhere on the board
Col7: SW_6.2, SW_B1.2, SW_G1.2, SW_SPACE1.2, SW_T1.2; also elsewhere on the board
Col8: SW_7.2, SW_F5.2, SW_H1.2, SW_N1.2, SW_Y1.2; also elsewhere on the board
Col9: SW_8.2, SW_F6.2, SW_J1.2, SW_M1.2, SW_U1.2; also elsewhere on the board
Col10: SW_9.2, SW_COMMA1.2, SW_F7.2, SW_I1.2, SW_K1.2; also elsewhere on the board
Col11: SW_10.2, SW_F8.2, SW_L1.2, SW_O1.2, SW_PERIOD1.2, SW_RALT1.2; also elsewhere on the board
Col12: SW_COLON1.2, SW_F9.2, SW_FSLASH1.2, SW_FUNC1.2, SW_P1.2, SW_UNDSCR1.2; also elsewhere on the board
Col13: SW_EQUAL1.2, SW_F10.2, SW_LBRACE1.2, SW_QUOT1.2; also elsewhere on the board
Col14: SW_ENTER1.2, SW_F11.2, SW_RBRACE1.2, SW_RSHIFT1.2, SW_RSUP1.2; also elsewhere on the board
Col15: SW_BKSPC1.2, SW_BSLSH1.2, SW_F12.2, SW_RCTL1.2; also elsewhere on the board
Col16: SW_DEL1.2, SW_INS1.2, SW_LEFT1.2, SW_PRINT1.2; also elsewhere on the board
Col17: SW_DOWN1.2, SW_END1.2, SW_HOME1.2, SW_SCROLL1.2, SW_UP1.2; also elsewhere on the board
Col18: SW_PAUSE1.2, SW_PGDN1.2, SW_PGUP1.2, SW_RIGHT1.2; also elsewhere on the board
unnamed: D1.2 (A), SW_ESC1.1
unnamed: D2.2 (A), SW_TILDE1.1
unnamed: D3.2 (A), SW_LCTRL1.1
unnamed: D4.2 (A), SW_TAB1.1
unnamed: D5.2 (A), SW_CAPS1.1
unnamed: D6.2 (A), SW_LSHIFT1.1
unnamed: D7.2 (A), SW_1.1
unnamed: D8.2 (A), SW_LSUP1.1
unnamed: D9.2 (A), SW_Q1.1
unnamed: D10.2 (A), SW_A1.1
unnamed: D11.2 (A), SW_F1.1
unnamed: D12.2 (A), SW_2.1
unnamed: D13.2 (A), SW_Z1.1
unnamed: D14.2 (A), SW_W1.1
unnamed: D15.2 (A), SW_LALT1.1
unnamed: D16.2 (A), SW_S1.1
unnamed: D17.2 (A), SW_F2.1
unnamed: D18.2 (A), SW_3.1
unnamed: D19.2 (A), SW_X1.1
unnamed: D20.2 (A), SW_E1.1
unnamed: D21.2 (A), SW_D1.1
unnamed: D22.2 (A), SW_F3.1
unnamed: D23.2 (A), SW_4.1
unnamed: D24.2 (A), SW_C1.1
unnamed: D25.2 (A), SW_R1.1
unnamed: D26.2 (A), SW_F0.1
unnamed: D27.2 (A), SW_F4.1
unnamed: D28.2 (A), SW_5.1
unnamed: D29.2 (A), SW_V1.1
unnamed: D30.2 (A), SW_T1.1
unnamed: D31.2 (A), SW_G1.1
unnamed: D32.2 (A), SW_6.1
unnamed: D33.2 (A), SW_B1.1
unnamed: D34.2 (A), SW_SPACE1.1
unnamed: D35.2 (A), SW_F5.1
unnamed: D36.2 (A), SW_Y1.1
unnamed: D37.2 (A), SW_H1.1
unnamed: D38.2 (A), SW_7.1
unnamed: D39.2 (A), SW_N1.1
unnamed: D40.2 (A), SW_F6.1
unnamed: D41.2 (A), SW_U1.1
unnamed: D42.2 (A), SW_J1.1
unnamed: D43.2 (A), SW_8.1
unnamed: D44.2 (A), SW_M1.1
unnamed: D45.2 (A), SW_F7.1
unnamed: D46.2 (A), SW_I1.1
unnamed: D47.2 (A), SW_K1.1
unnamed: D48.2 (A), SW_9.1
unnamed: D49.2 (A), SW_COMMA1.1
unnamed: D50.2 (A), SW_F8.1
unnamed: D51.2 (A), SW_O1.1
unnamed: D52.2 (A), SW_L1.1
unnamed: D53.2 (A), SW_10.1
unnamed: D54.2 (A), SW_RALT1.1
unnamed: D55.2 (A), SW_PERIOD1.1
unnamed: D56.2 (A), SW_P1.1
unnamed: D57.2 (A), SW_COLON1.1
unnamed: D58.2 (A), SW_F9.1
unnamed: D59.2 (A), SW_UNDSCR1.1
unnamed: D60.2 (A), SW_FSLASH1.1
unnamed: D61.2 (A), SW_FUNC1.1
unnamed: D62.2 (A), SW_LBRACE1.1
unnamed: D63.2 (A), SW_QUOT1.1
unnamed: D64.2 (A), SW_F10.1
unnamed: D65.2 (A), SW_EQUAL1.1
unnamed: D66.2 (A), SW_RBRACE1.1
unnamed: D67.2 (A), SW_RSUP1.1
unnamed: D68.2 (A), SW_F11.1
unnamed: D69.2 (A), SW_RSHIFT1.1
unnamed: D70.2 (A), SW_ENTER1.1
unnamed: D71.2 (A), SW_BKSPC1.1
unnamed: D72.2 (A), SW_BSLSH1.1
unnamed: D73.2 (A), SW_RCTL1.1
unnamed: D74.2 (A), SW_F12.1
unnamed: D75.2 (A), SW_PRINT1.1
unnamed: D76.2 (A), SW_INS1.1
unnamed: D77.2 (A), SW_DEL1.1
unnamed: D78.2 (A), SW_LEFT1.1
unnamed: D79.2 (A), SW_SCROLL1.1
unnamed: D80.2 (A), SW_HOME1.1
unnamed: D81.2 (A), SW_END1.1
unnamed: D82.2 (A), SW_UP1.1
unnamed: D83.2 (A), SW_DOWN1.1
unnamed: D84.2 (A), SW_PAUSE1.1
unnamed: D85.2 (A), SW_PGUP1.1
unnamed: D86.2 (A), SW_PGDN1.1
unnamed: D87.2 (A), SW_RIGHT1.1
Row1: D1.1 (K), D11.1 (K), D17.1 (K), D22.1 (K), D27.1 (K), D35.1 (K), D40.1 (K), D45.1 (K), D50.1 (K), D58.1 (K), D64.1 (K), D68.1 (K), D74.1 (K), D75.1 (K), D79.1 (K), D84.1 (K); also elsewhere on the board
Row2: D2.1 (K), D7.1 (K), D12.1 (K), D18.1 (K), D23.1 (K), D28.1 (K), D32.1 (K), D38.1 (K), D43.1 (K), D48.1 (K), D53.1 (K), D59.1 (K), D65.1 (K), D71.1 (K), D76.1 (K), D80.1 (K), D85.1 (K); also elsewhere on the board
Row3: D4.1 (K), D9.1 (K), D14.1 (K), D20.1 (K), D25.1 (K), D30.1 (K), D36.1 (K), D41.1 (K), D46.1 (K), D51.1 (K), D56.1 (K), D62.1 (K), D66.1 (K), D72.1 (K), D77.1 (K), D81.1 (K), D86.1 (K); also elsewhere on the board
Row4: D5.1 (K), D10.1 (K), D16.1 (K), D21.1 (K), D26.1 (K), D31.1 (K), D37.1 (K), D42.1 (K), D47.1 (K), D52.1 (K), D57.1 (K), D63.1 (K), D70.1 (K); also elsewhere on the board
Row5: D6.1 (K), D13.1 (K), D19.1 (K), D24.1 (K), D29.1 (K), D33.1 (K), D39.1 (K), D44.1 (K), D49.1 (K), D55.1 (K), D60.1 (K), D69.1 (K), D82.1 (K); also elsewhere on the board
Row6: D3.1 (K), D8.1 (K), D15.1 (K), D34.1 (K), D54.1 (K), D61.1 (K), D67.1 (K), D73.1 (K), D78.1 (K), D83.1 (K), D87.1 (K); also elsewhere on the board

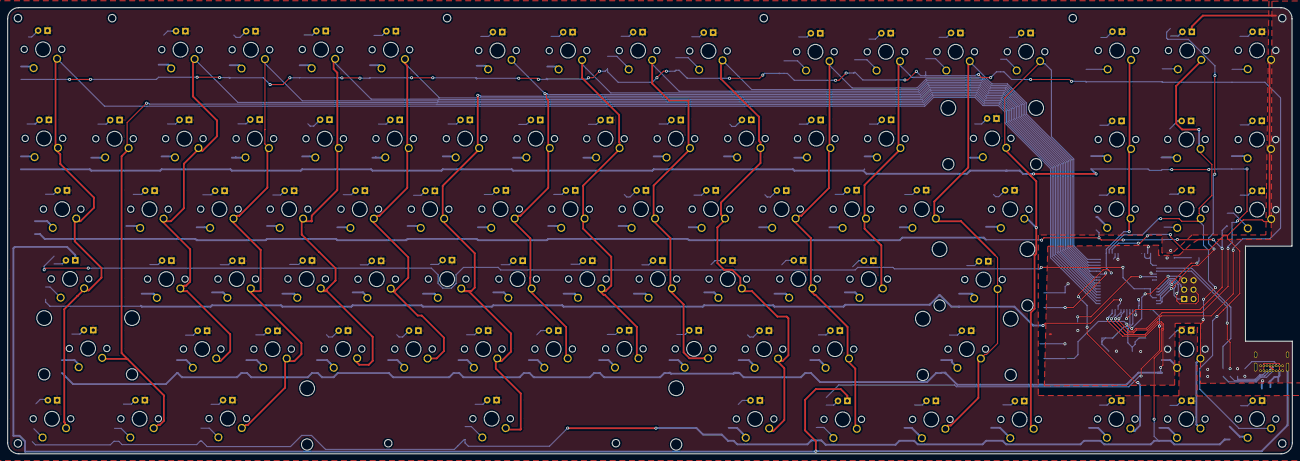
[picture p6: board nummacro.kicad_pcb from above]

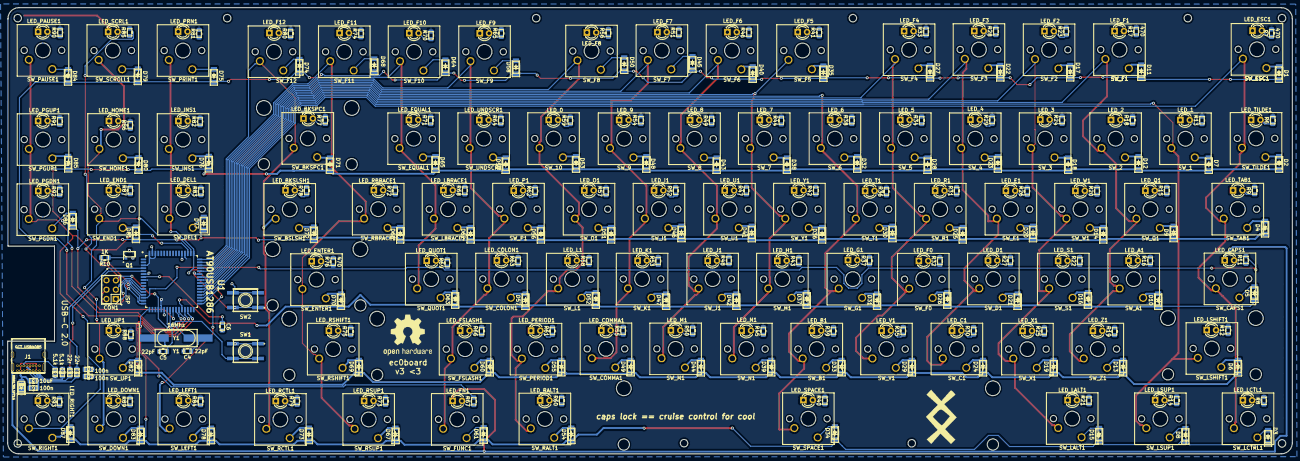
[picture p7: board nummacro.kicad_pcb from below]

Board: 2 copper layers, 348.1 x 120.9 mm, 368 parts (194 on the bottom side), 221 nets.

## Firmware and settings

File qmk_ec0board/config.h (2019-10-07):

/*
Copyright 2018 ec0 <james@ec0.io>

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
You should have received a copy of the GNU General Public License
along with this program.  If not, see <http://www.gnu.org/licenses/>.
*/

#ifndef CONFIG_H
#define CONFIG_H

#include "config_common.h"

/* Using generic HID compliant vendor ID
https://github.com/obdev/v-usb/blob/master/usbdrv/USB-IDs-for-free.txt
*/
#define VENDOR_ID       0x16c0
#define PRODUCT_ID      0x05df
#define DEVICE_VER      0x0001
#define MANUFACTURER    ec0
#define PRODUCT         ec0board v3
#define DESCRIPTION     QMK keyboard firmware for ec0v3

/* 7 Rows of 18 keys, roughly */
#define MATRIX_ROWS 6
#define MATRIX_COLS 18

/* Row and column pins non-contiguous for PCB layout reasons */
#define MATRIX_ROW_PINS { D2, D1, D0, D3, D4, D5 }
#define MATRIX_COL_PINS { E0, E1, C0, C1, C2, C3, C4, C5, C6, C7, A7, A6, A5, A4, A3, A2, A1, A0 }
#define UNUSED_PINS

/* COL2ROW or ROW2COL */
#define DIODE_DIRECTION COL2ROW

/* number of backlight levels */
#define BACKLIGHT_PIN B5
#ifdef BACKLIGHT_PIN
#define BACKLIGHT_LEVELS 6
#endif

/* Set 0 if debouncing isn't needed */
#define DEBOUNCING_DELAY 5

/* Mechanical locking support. Use KC_LCAP, KC_LNUM or KC_LSCR instead in keymap */
#define LOCKING_SUPPORT_ENABLE

/* Locking resynchronize hack */
#define LOCKING_RESYNC_ENABLE

/* key combination for command */
#define IS_COMMAND() ( \
    keyboard_report->mods == (MOD_BIT(KC_LSHIFT) | MOD_BIT(KC_RSHIFT)) \
)

/* prevent stuck modifiers */
#define PREVENT_STUCK_MODIFIERS

#endif

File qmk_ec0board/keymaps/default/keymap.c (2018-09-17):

#include QMK_KEYBOARD_H

// Each layer gets a name for readability, which is then used in the keymap matrix below.
// The underscores don't mean anything - you can have a layer called STUFF or any other name.
// Layer names don't all need to be of the same length, obviously, and you can also skip them
// entirely and just use numbers.
#define _BL 0
#define _FL1 1
#define _FL2 2

const uint16_t PROGMEM keymaps[][MATRIX_ROWS][MATRIX_COLS] = {

	KEYMAP(
		KC_ESC, KC_F1, KC_F2, KC_F3, KC_F4, KC_F5, KC_F6, KC_F7, KC_F8, KC_F9, KC_F10, KC_F11, KC_F12, KC_PSCR, KC_SLCK, KC_PAUS, 
		
		KC_GRV, KC_1, KC_2, KC_3, KC_4, KC_5, KC_6, KC_7, KC_8, KC_9, KC_0, KC_MINS, KC_EQL, KC_BSPC, KC_INS, KC_HOME, KC_PGUP, 
		KC_TAB, KC_Q, KC_W, KC_E, KC_R, KC_T, KC_Y, KC_U, KC_I, KC_O, KC_P, KC_LBRC, KC_RBRC, KC_BSLS, KC_DEL, KC_END, KC_PGDN, 
		KC_CAPS, KC_A, KC_S, KC_D, KC_F, KC_G, KC_H, KC_J, KC_K, KC_L, KC_SCLN, KC_QUOT, KC_ENT, 
		KC_LSFT, KC_Z, KC_X, KC_C, KC_V, KC_B, KC_N, KC_M, KC_COMM, KC_DOT, KC_SLSH, KC_LSFT, KC_NO, 
		KC_LCTL, KC_LGUI, KC_LALT, KC_SPC, KC_LALT, KC_LGUI, KC_MENU, KC_LCTL, KC_NO, KC_NO, KC_NO),

	KEYMAP(
		KC_TRNS, KC_TRNS, KC_TRNS, KC_TRNS, KC_TRNS, KC_TRNS, KC_TRNS, KC_TRNS, KC_TRNS, KC_TRNS, KC_TRNS, KC_TRNS, KC_TRNS, KC_TRNS, KC_TRNS, KC_TRNS, 
		
		KC_TRNS, KC_TRNS, KC_TRNS, KC_TRNS, KC_TRNS, KC_TRNS, KC_TRNS, KC_TRNS, KC_TRNS, KC_TRNS, KC_TRNS, KC_TRNS, KC_TRNS, KC_TRNS, KC_TRNS, KC_TRNS, KC_TRNS, 
		KC_TRNS, KC_TRNS, KC_TRNS, KC_TRNS, KC_TRNS, KC_TRNS, KC_TRNS, KC_TRNS, KC_TRNS, KC_TRNS, KC_TRNS, KC_TRNS, KC_TRNS, KC_TRNS, KC_TRNS, KC_TRNS, KC_TRNS, 
		KC_TRNS, KC_TRNS, KC_TRNS, KC_TRNS, KC_TRNS, KC_TRNS, KC_TRNS, KC_TRNS, KC_TRNS, KC_TRNS, KC_TRNS, KC_TRNS, KC_TRNS, 
		KC_TRNS, KC_TRNS, KC_TRNS, KC_TRNS, KC_TRNS, KC_TRNS, KC_TRNS, KC_TRNS, KC_TRNS, KC_TRNS, KC_TRNS, KC_TRNS, KC_TRNS, 
		KC_TRNS, KC_TRNS, KC_TRNS, KC_TRNS, KC_TRNS, KC_TRNS, KC_TRNS, KC_TRNS, KC_TRNS, KC_TRNS, KC_TRNS),

	KEYMAP(
		KC_TRNS, KC_TRNS, KC_TRNS, KC_TRNS, KC_TRNS, KC_TRNS, KC_TRNS, KC_TRNS, KC_TRNS, KC_TRNS, KC_TRNS, KC_TRNS, KC_TRNS, KC_TRNS, KC_TRNS, KC_TRNS, 
		
		KC_TRNS, KC_TRNS, KC_TRNS, KC_TRNS, KC_TRNS, KC_TRNS, KC_TRNS, KC_TRNS, KC_TRNS, KC_TRNS, KC_TRNS, KC_TRNS, KC_TRNS, KC_TRNS, KC_TRNS, KC_TRNS, KC_TRNS, 
		KC_TRNS, KC_TRNS, KC_TRNS, KC_TRNS, KC_TRNS, KC_TRNS, KC_TRNS, KC_TRNS, KC_TRNS, KC_TRNS, KC_TRNS, KC_TRNS, KC_TRNS, KC_TRNS, KC_TRNS, KC_TRNS, KC_TRNS, 
		KC_TRNS, KC_TRNS, KC_TRNS, KC_TRNS, KC_TRNS, KC_TRNS, KC_TRNS, KC_TRNS, KC_TRNS, KC_TRNS, KC_TRNS, KC_TRNS, KC_TRNS, 
		KC_TRNS, KC_TRNS, KC_TRNS, KC_TRNS, KC_TRNS, KC_TRNS, KC_TRNS, KC_TRNS, KC_TRNS, KC_TRNS, KC_TRNS, KC_TRNS, KC_TRNS, 
		KC_TRNS, KC_TRNS, KC_TRNS, KC_TRNS, KC_TRNS, KC_TRNS, KC_TRNS, KC_TRNS, KC_TRNS, KC_TRNS, KC_TRNS),

	KEYMAP(
		KC_TRNS, KC_TRNS, KC_TRNS, KC_TRNS, KC_TRNS, KC_TRNS, KC_TRNS, KC_TRNS, KC_TRNS, KC_TRNS, KC_TRNS, KC_TRNS, KC_TRNS, KC_TRNS, KC_TRNS, KC_TRNS, 
		
		KC_TRNS, KC_TRNS, KC_TRNS, KC_TRNS, KC_TRNS, KC_TRNS, KC_TRNS, KC_TRNS, KC_TRNS, KC_TRNS, KC_TRNS, KC_TRNS, KC_TRNS, KC_TRNS, KC_TRNS, KC_TRNS, KC_TRNS, 
		KC_TRNS, KC_TRNS, KC_TRNS, KC_TRNS, KC_TRNS, KC_TRNS, KC_TRNS, KC_TRNS, KC_TRNS, KC_TRNS, KC_TRNS, KC_TRNS, KC_TRNS, KC_TRNS, KC_TRNS, KC_TRNS, KC_TRNS, 
		KC_TRNS, KC_TRNS, KC_TRNS, KC_TRNS, KC_TRNS, KC_TRNS, KC_TRNS, KC_TRNS, KC_TRNS, KC_TRNS, KC_TRNS, KC_TRNS, KC_TRNS, 
		KC_TRNS, KC_TRNS, KC_TRNS, KC_TRNS, KC_TRNS, KC_TRNS, KC_TRNS, KC_TRNS, KC_TRNS, KC_TRNS, KC_TRNS, KC_TRNS, KC_TRNS, 
		KC_TRNS, KC_TRNS, KC_TRNS, KC_TRNS, KC_TRNS, KC_TRNS, KC_TRNS, KC_TRNS, KC_TRNS, KC_TRNS, KC_TRNS),

	KEYMAP(
		KC_TRNS, KC_TRNS, KC_TRNS, KC_TRNS, KC_TRNS, KC_TRNS, KC_TRNS, KC_TRNS, KC_TRNS, KC_TRNS, KC_TRNS, KC_TRNS, KC_TRNS, KC_TRNS, KC_TRNS, KC_TRNS, 
		
		KC_TRNS, KC_TRNS, KC_TRNS, KC_TRNS, KC_TRNS, KC_TRNS, KC_TRNS, KC_TRNS, KC_TRNS, KC_TRNS, KC_TRNS, KC_TRNS, KC_TRNS, KC_TRNS, KC_TRNS, KC_TRNS, KC_TRNS, 
		KC_TRNS, KC_TRNS, KC_TRNS, KC_TRNS, KC_TRNS, KC_TRNS, KC_TRNS, KC_TRNS, KC_TRNS, KC_TRNS, KC_TRNS, KC_TRNS, KC_TRNS, KC_TRNS, KC_TRNS, KC_TRNS, KC_TRNS, 
		KC_TRNS, KC_TRNS, KC_TRNS, KC_TRNS, KC_TRNS, KC_TRNS, KC_TRNS, KC_TRNS, KC_TRNS, KC_TRNS, KC_TRNS, KC_TRNS, KC_TRNS, 
		KC_TRNS, KC_TRNS, KC_TRNS, KC_TRNS, KC_TRNS, KC_TRNS, KC_TRNS, KC_TRNS, KC_TRNS, KC_TRNS, KC_TRNS, KC_TRNS, KC_TRNS, 
		KC_TRNS, KC_TRNS, KC_TRNS, KC_TRNS, KC_TRNS, KC_TRNS, KC_TRNS, KC_TRNS, KC_TRNS, KC_TRNS, KC_TRNS),

	KEYMAP(
		KC_TRNS, KC_TRNS, KC_TRNS, KC_TRNS, KC_TRNS, KC_TRNS, KC_TRNS, KC_TRNS, KC_TRNS, KC_TRNS, KC_TRNS, KC_TRNS, KC_TRNS, KC_TRNS, KC_TRNS, KC_TRNS, 
		
		KC_TRNS, KC_TRNS, KC_TRNS, KC_TRNS, KC_TRNS, KC_TRNS, KC_TRNS, KC_TRNS, KC_TRNS, KC_TRNS, KC_TRNS, KC_TRNS, KC_TRNS, KC_TRNS, KC_TRNS, KC_TRNS, KC_TRNS, 
		KC_TRNS, KC_TRNS, KC_TRNS, KC_TRNS, KC_TRNS, KC_TRNS, KC_TRNS, KC_TRNS, KC_TRNS, KC_TRNS, KC_TRNS, KC_TRNS, KC_TRNS, KC_TRNS, KC_TRNS, KC_TRNS, KC_TRNS, 
		KC_TRNS, KC_TRNS, KC_TRNS, KC_TRNS, KC_TRNS, KC_TRNS, KC_TRNS, KC_TRNS, KC_TRNS, KC_TRNS, KC_TRNS, KC_TRNS, KC_TRNS, 
		KC_TRNS, KC_TRNS, KC_TRNS, KC_TRNS, KC_TRNS, KC_TRNS, KC_TRNS, KC_TRNS, KC_TRNS, KC_TRNS, KC_TRNS, KC_TRNS, KC_TRNS, 
		KC_TRNS, KC_TRNS, KC_TRNS, KC_TRNS, KC_TRNS, KC_TRNS, KC_TRNS, KC_TRNS, KC_TRNS, KC_TRNS, KC_TRNS),

	KEYMAP(
		KC_TRNS, KC_TRNS, KC_TRNS, KC_TRNS, KC_TRNS, KC_TRNS, KC_TRNS, KC_TRNS, KC_TRNS, KC_TRNS, KC_TRNS, KC_TRNS, KC_TRNS, KC_TRNS, KC_TRNS, KC_TRNS, 
		
		KC_TRNS, KC_TRNS, KC_TRNS, KC_TRNS, KC_TRNS, KC_TRNS, KC_TRNS, KC_TRNS, KC_TRNS, KC_TRNS, KC_TRNS, KC_TRNS, KC_TRNS, KC_TRNS, KC_TRNS, KC_TRNS, KC_TRNS, 
		KC_TRNS, KC_TRNS, KC_TRNS, KC_TRNS, KC_TRNS, KC_TRNS, KC_TRNS, KC_TRNS, KC_TRNS, KC_TRNS, KC_TRNS, KC_TRNS, KC_TRNS, KC_TRNS, KC_TRNS, KC_TRNS, KC_TRNS, 
		KC_TRNS, KC_TRNS, KC_TRNS, KC_TRNS, KC_TRNS, KC_TRNS, KC_TRNS, KC_TRNS, KC_TRNS, KC_TRNS, KC_TRNS, KC_TRNS, KC_TRNS, 
		KC_TRNS, KC_TRNS, KC_TRNS, KC_TRNS, KC_TRNS, KC_TRNS, KC_TRNS, KC_TRNS, KC_TRNS, KC_TRNS, KC_TRNS, KC_TRNS, KC_TRNS, 
		KC_TRNS, KC_TRNS, KC_TRNS, KC_TRNS, KC_TRNS, KC_TRNS, KC_TRNS, KC_TRNS, KC_TRNS, KC_TRNS, KC_TRNS),

	KEYMAP(
		KC_TRNS, KC_TRNS, KC_TRNS, KC_TRNS, KC_TRNS, KC_TRNS, KC_TRNS, KC_TRNS, KC_TRNS, KC_TRNS, KC_TRNS, KC_TRNS, KC_TRNS, KC_TRNS, KC_TRNS, KC_TRNS, 
		
		KC_TRNS, KC_TRNS, KC_TRNS, KC_TRNS, KC_TRNS, KC_TRNS, KC_TRNS, KC_TRNS, KC_TRNS, KC_TRNS, KC_TRNS, KC_TRNS, KC_TRNS, KC_TRNS, KC_TRNS, KC_TRNS, KC_TRNS, 
		KC_TRNS, KC_TRNS, KC_TRNS, KC_TRNS, KC_TRNS, KC_TRNS, KC_TRNS, KC_TRNS, KC_TRNS, KC_TRNS, KC_TRNS, KC_TRNS, KC_TRNS, KC_TRNS, KC_TRNS, KC_TRNS, KC_TRNS, 
		KC_TRNS, KC_TRNS, KC_TRNS, KC_TRNS, KC_TRNS, KC_TRNS, KC_TRNS, KC_TRNS, KC_TRNS, KC_TRNS, KC_TRNS, KC_TRNS, KC_TRNS, 
		KC_TRNS, KC_TRNS, KC_TRNS, KC_TRNS, KC_TRNS, KC_TRNS, KC_TRNS, KC_TRNS, KC_TRNS, KC_TRNS, KC_TRNS, KC_TRNS, KC_TRNS, 
		KC_TRNS, KC_TRNS, KC_TRNS, KC_TRNS, KC_TRNS, KC_TRNS, KC_TRNS, KC_TRNS, KC_TRNS, KC_TRNS, KC_TRNS),
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

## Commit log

2018-09-17 Initial commit of v2 ec0board
    [controller.sch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]
2018-09-17 Added BOM and README
    [nummacro.csv]
2018-09-17 Fixed table formatting for BOM
2018-09-17 Added QMK board files
2018-09-17 Added fuse info
2019-05-25 Moved to stock KiCad MX buttons and LEDs, cleaned up routing, added a USB-C connection to replace the flimsy Micro-USB, Updated for latest KiCad
    [backlight.sch, controller-2019-04-01-09-29-31.sch, keymatrix.sch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]
2019-08-31 Rerouted, migrated to standard KiCad keyboard footprints, moved to USB-C to address durability issues. Added holed for PCB-mounted stabilisers for standalone usage.
    [USB4085-GF-A.stl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]
2019-08-31 Updated drill and pos files
    [nummacro-NPTH.drl, nummacro-PTH.drl]
2019-08-31 Regenerated all gerbers and drill files, removed duplicates
    [nummacro-B.Cu.gbr, nummacro-B.Mask.gbr, nummacro-B.SilkS.gbr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]
2019-08-31 WIP USB-C 3d model, cleaned up main key matrix routing quite a bit
    [USB4085-GF-A.stp, nummacro.kicad_pcb]
2019-08-31 Silkscreen overhaul to move everything to the back layer, moved diode symbols to silkscreen from fab layer. Regenerated gerbs.
    [nummacro-B_Cu.gbr, nummacro-B_Mask.gbr, nummacro-B_SilkS.gbr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]
2019-10-07 v3 initial commit, USB-C, interactive BOM, rerouted and changed to use standard KiCad libs where possible
    [backlight.sch, controller.sch, keymatrix.sch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]
2019-10-07 v3 Gerbers
    [nummacro-B_Cu.gbr, nummacro-B_Mask.gbr, nummacro-B_SilkS.gbr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]

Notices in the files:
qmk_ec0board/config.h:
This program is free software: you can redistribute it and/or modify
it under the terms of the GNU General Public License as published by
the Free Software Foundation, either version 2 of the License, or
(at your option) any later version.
